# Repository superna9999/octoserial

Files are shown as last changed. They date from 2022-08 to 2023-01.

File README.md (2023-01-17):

# OctoSerial

USB High-Speed to 8x RS-232 TTL level with the CH348Q IC.

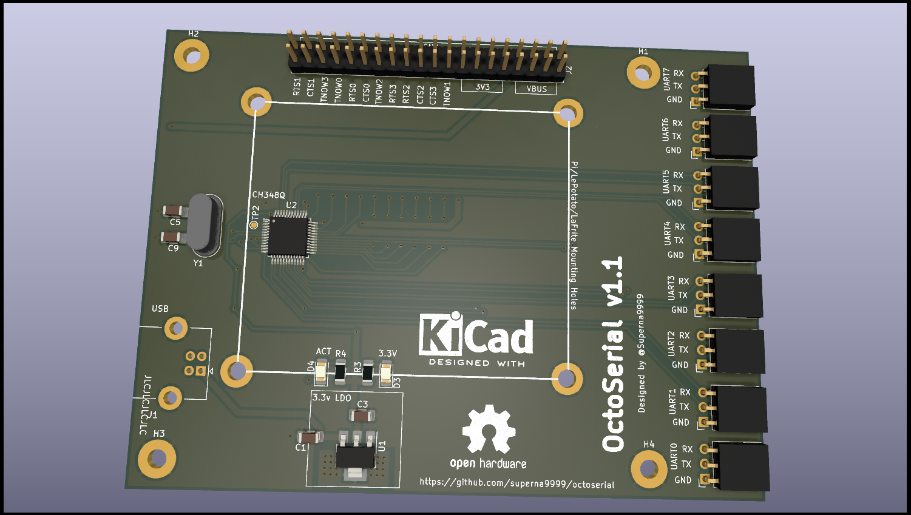
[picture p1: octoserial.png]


Schematics: [octoserial.pdf](octoserial.pdf)

Changelog
---------

Version 1.1:
- Production version with 40pins headers with GPIOs + 3v3 + VBUS & GND

Version 0.1:
- Initial prototype with CH348Q samples

LICENCE
-------

```
Apache License Version 2.0
```

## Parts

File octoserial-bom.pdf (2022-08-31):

octoserial.csv

Page 1

Designator | Package | Quantity Designation
C1,C3 | C_1206_3216Metric_Pad1.33x1.80mm_HandSolder | 2 10uF
U1 | SOT-223-3_TabPin2 | 1 AMS1117-3.3
Y1 | Crystal_HC49-4H_Vertical | 1 8MHz
U2 | LQFP-48_7x7mm_P0.5mm | 1 CH348Q
C9,C5 | C_1206_3216Metric_Pad1.33x1.80mm_HandSolder | 2 22pF
D3,D4 | LED_1206_3216Metric_Pad1.42x1.75mm_HandSolder | 2 LED
R3,R4 | R_1206_3216Metric_Pad1.30x1.75mm_HandSolder | 2 2K
J1 | USB_B_Lumberg_2411_02_Horizontal | 1 USB_OTG
C2,C15,C16,C17,C14 C_1206_3216Metric_Pad1.33x1.80mm_HandSolder | 4 100nF
R1,R2 | R_1206_3216Metric_Pad1.30x1.75mm_HandSolder | 2 4.7K

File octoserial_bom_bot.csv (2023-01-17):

Comment | Designator | Footprint | LCSC Part #
0.1uF | C2 | 1206 | C110255
100nF | C14 C15 C16 C17 | 1206 | C110255
4.7K | R1 R2 | 1206 | C17936

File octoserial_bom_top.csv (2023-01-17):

Comment | Designator | Footprint | LCSC Part #
10uF | C1 C3 | 1206 | C13585
22pF | C5 C9 | 1206 | C5137630
LED | D3 | 1206
LED | D4 | 1206 | C434438
USB_OTG | J1 |  | C46392
Conn_02x20_Odd_Even | J2 |  | C124383
Conn_01x03_Male | J3 J4 J5 J6 J7 J8 J9 J10 |  | C5116482
2K | R3 R4 | 1206 | C17944
AMS1117-3.3 | U1 | SOT-223-3 | C173386
CH348Q | U2 |  | C2979161
8MHz | Y1 |  | C21263

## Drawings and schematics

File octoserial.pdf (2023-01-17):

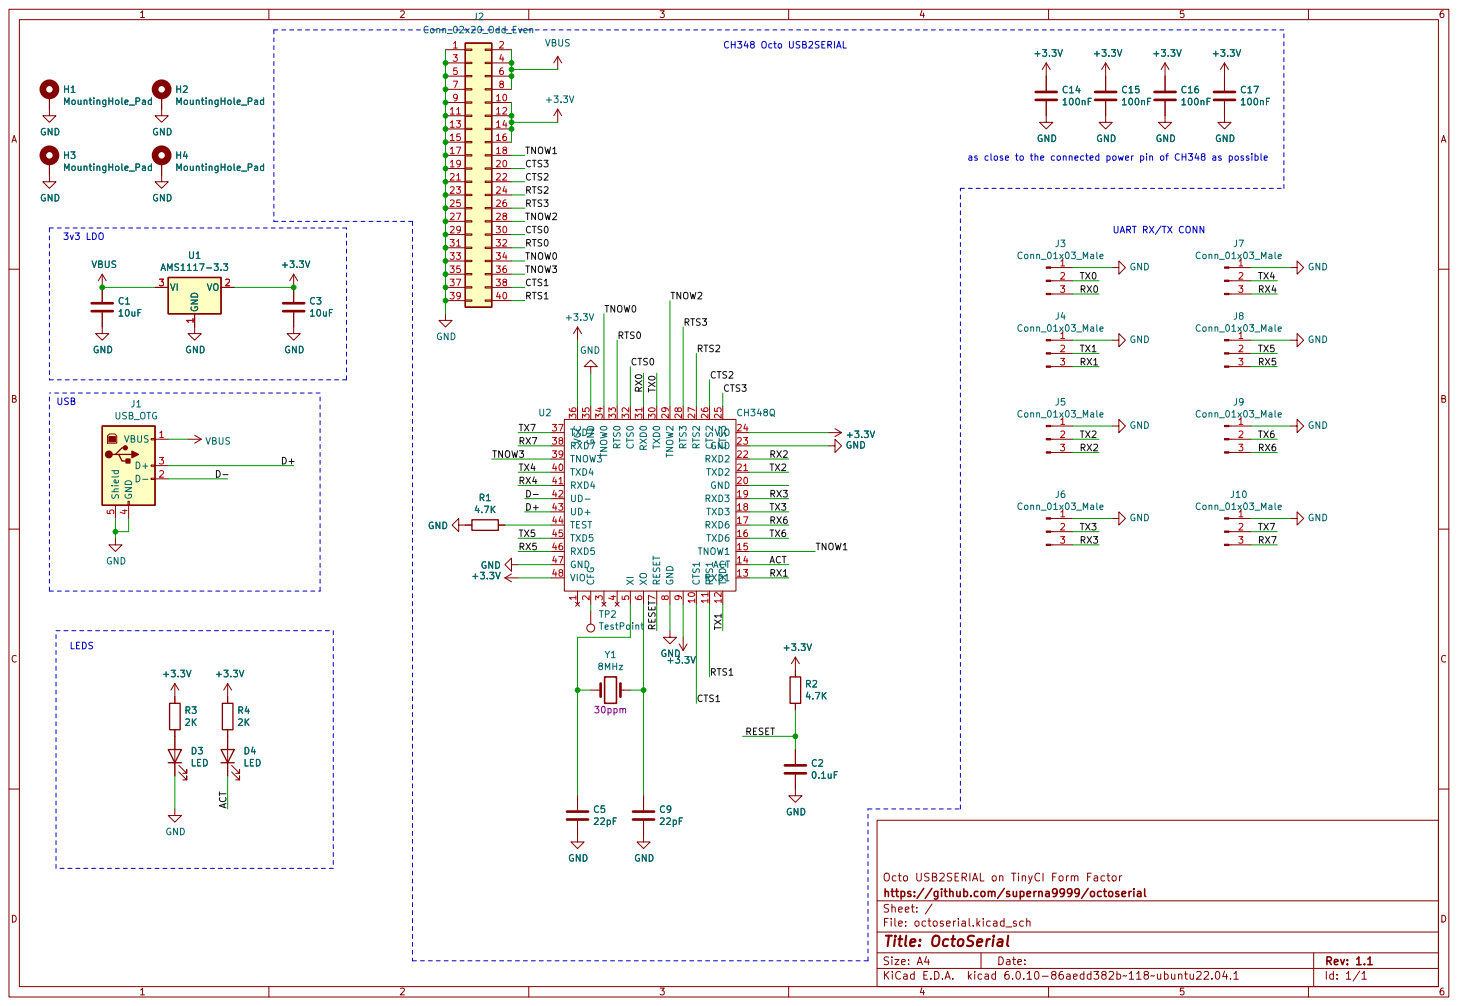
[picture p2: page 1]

9 | 10
11 | 12
13 | 14
15 | 16
17 | 18
19 | 20
21 | 22

as close to the connected power pin of CH348 as possible UART RX/TX CONN

25 | 26
27 | 28
29 | 30
31 | 32
33 | 34
35 | 36
37 | 38

3v3 LDO | +3.3V 10uF GND 10uF GND

4 TXD4 40 RXD4 41 UD- 42 UD+ 43 TEST 44 TXD5 45 RXD5 46 GND 47 VIO 48 XI 5 XO

Octo USB2SERIAL on TinyCI Form Factor
File: octoserial.kicad_sch Sheet: / https://github.com/superna9999/octoserial

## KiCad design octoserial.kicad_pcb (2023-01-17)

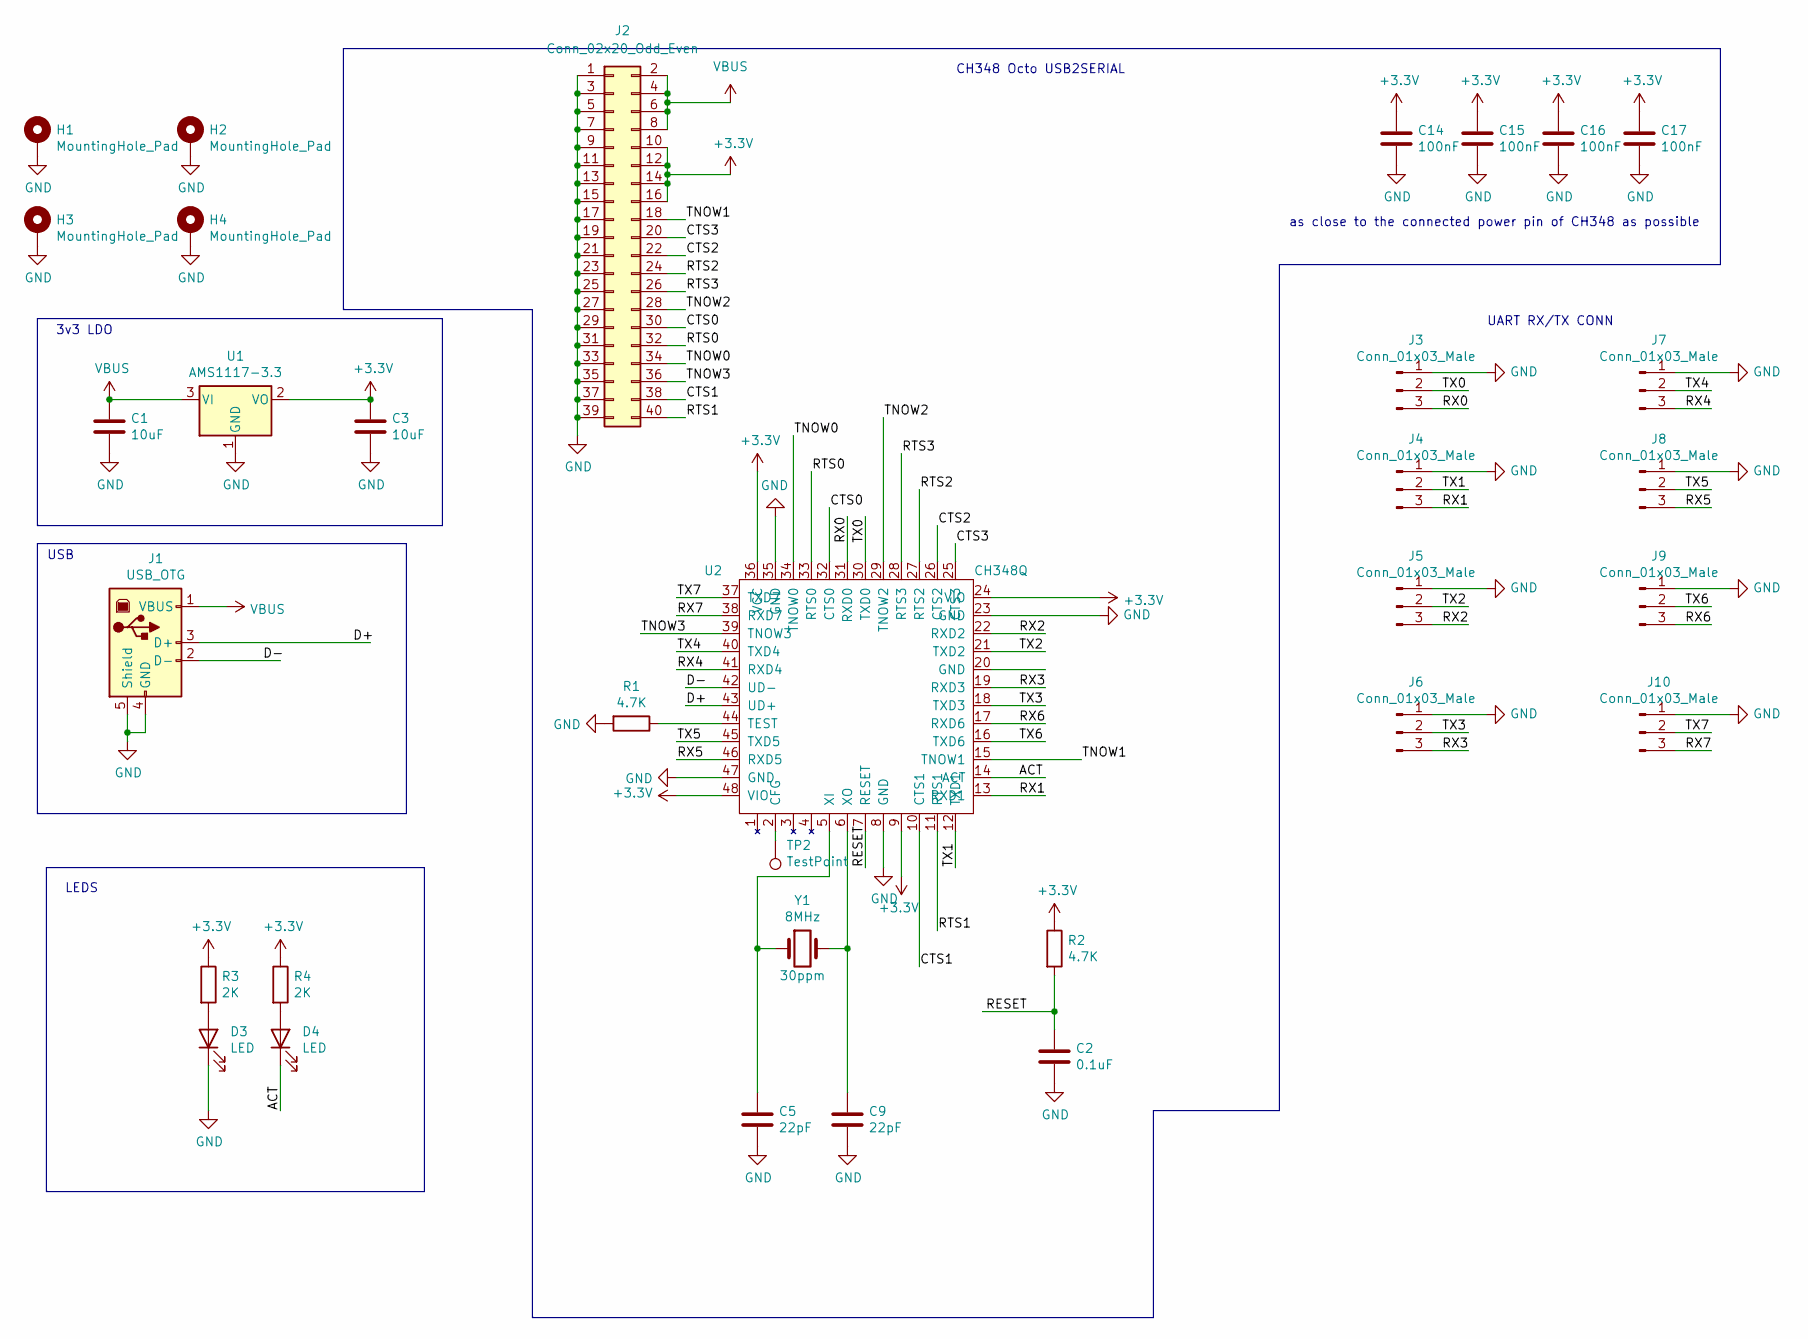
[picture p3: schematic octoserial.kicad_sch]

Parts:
C1, C3: 10uF; C_1206_3216Metric_Pad1.33x1.80mm_HandSolder; JLC 1206
C2: 0.1uF; C_1206_3216Metric_Pad1.33x1.80mm_HandSolder; JLC 1206
C5, C9: 22pF; C_1206_3216Metric_Pad1.33x1.80mm_HandSolder; JLC 1206
C14, C15, C16, C17: 100nF; C_1206_3216Metric_Pad1.33x1.80mm_HandSolder; JLC 1206
D3, D4: LED; LED_1206_3216Metric_Pad1.42x1.75mm_HandSolder; JLC 1206
H1, H2, H3, H4: MountingHole_Pad; MountingHole_3.2mm_M3_Pad
J1: USB_OTG; USB_B_Lumberg_2411_02_Horizontal; LCSC C46392
J2: Conn_02x20_Odd_Even; PinHeader_2x20_P2.54mm_Vertical; LCSC C124383
J3, J4, J5, J6, J7, J8, J9, J10: Conn_01x03_Male; PinSocket_1x03_P2.54mm_Horizontal; LCSC C5116482
R1, R2: 4.7K; R_1206_3216Metric_Pad1.30x1.75mm_HandSolder; JLC 1206
R3, R4: 2K; R_1206_3216Metric_Pad1.30x1.75mm_HandSolder; JLC 1206
TP2: TestPoint; TestPoint_Pad_D1.0mm
U1: AMS1117-3.3; SOT-223-3_TabPin2; JLC SOT-223-3
U2: CH348Q; LQFP-48_7x7mm_P0.5mm; LCSC C2979161
Y1: 8MHz; Crystal_HC49-4H_Vertical; LCSC C21263

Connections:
+3V3: C3.1, C14.1, C15.1, C16.1, C17.1, J2.10, J2.12, J2.14, J2.16, R2.1, R3.1, R4.1, U1.2 (VO), U2.9, U2.24 (VIO), U2.36 (VCC), U2.48 (VIO)
/ACT: D4.1 (K), U2.14 (ACT)
/CTS0: J2.30, U2.32 (CTS0)
/CTS1: J2.38, U2.10 (CTS1)
/CTS2: J2.22, U2.26 (CTS2)
/CTS3: J2.20, U2.25 (CTS3)
/D+: J1.3 (D+), U2.43 (UD+)
/D-: J1.2 (D-), U2.42 (UD-)
/RESET: C2.1, R2.2, U2.7 (RESET)
/RTS0: J2.32, U2.33 (RTS0)
/RTS1: J2.40, U2.11 (RTS1)
/RTS2: J2.24, U2.27 (RTS2)
/RTS3: J2.26, U2.28 (RTS3)
/RX0: J3.3, U2.31 (RXD0)
/RX1: J4.3, U2.13 (RXD1)
/RX2: J5.3, U2.22 (RXD2)
/RX3: J6.3, U2.19 (RXD3)
/RX4: J7.3, U2.41 (RXD4)
/RX5: J8.3, U2.46 (RXD5)
/RX6: J9.3, U2.17 (RXD6)
/RX7: J10.3, U2.38 (RXD7)
/TNOW0: J2.34, U2.34 (TNOW0)
/TNOW1: J2.18, U2.15 (TNOW1)
/TNOW2: J2.28, U2.29 (TNOW2)
/TNOW3: J2.36, U2.39 (TNOW3)
/TX0: J3.2, U2.30 (TXD0)
/TX1: J4.2, U2.12 (TXD1)
/TX2: J5.2, U2.21 (TXD2)
/TX3: J6.2, U2.18 (TXD3)
/TX4: J7.2, U2.40 (TXD4)
/TX5: J8.2, U2.45 (TXD5)
/TX6: J9.2, U2.16 (TXD6)
/TX7: J10.2, U2.37 (TXD7)
GND: C1.2, C2.2, C3.2, C5.2, C9.2, C14.2, C15.2, C16.2, C17.2, D3.1 (K), H1.1, H2.1, H3.1, H4.1, J1.4 (GND), J1.5 (Shield), J2.1, J2.3, J2.5, J2.7, J2.9, J2.11, J2.13, J2.15, J2.17, J2.19, J2.21, J2.23, J2.25, J2.27, J2.29, J2.31, J2.33, J2.35, J2.37, J2.39, J3.1, J4.1, J5.1, J6.1, J7.1, J8.1, J9.1, J10.1, R1.2, U1.1 (GND), U2.8 (GND), U2.23 (GND), U2.35 (GND), U2.47 (GND)
unnamed: C5.1, U2.5 (XI), Y1.1
unnamed: C9.1, U2.6 (XO), Y1.2
unnamed: D3.2 (A), R3.2
unnamed: D4.2 (A), R4.2
unnamed: R1.1, U2.44 (TEST)
unnamed: TP2.1, U2.2 (CFG)
VBUS: C1.1, J1.1 (VBUS), J2.2, J2.4, J2.6, J2.8, U1.3 (VI)

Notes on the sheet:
LEDS
UART RX/TX CONN
3v3 LDO
USB
as close to the connected power pin of CH348 as possible
CH348 Octo USB2SERIAL

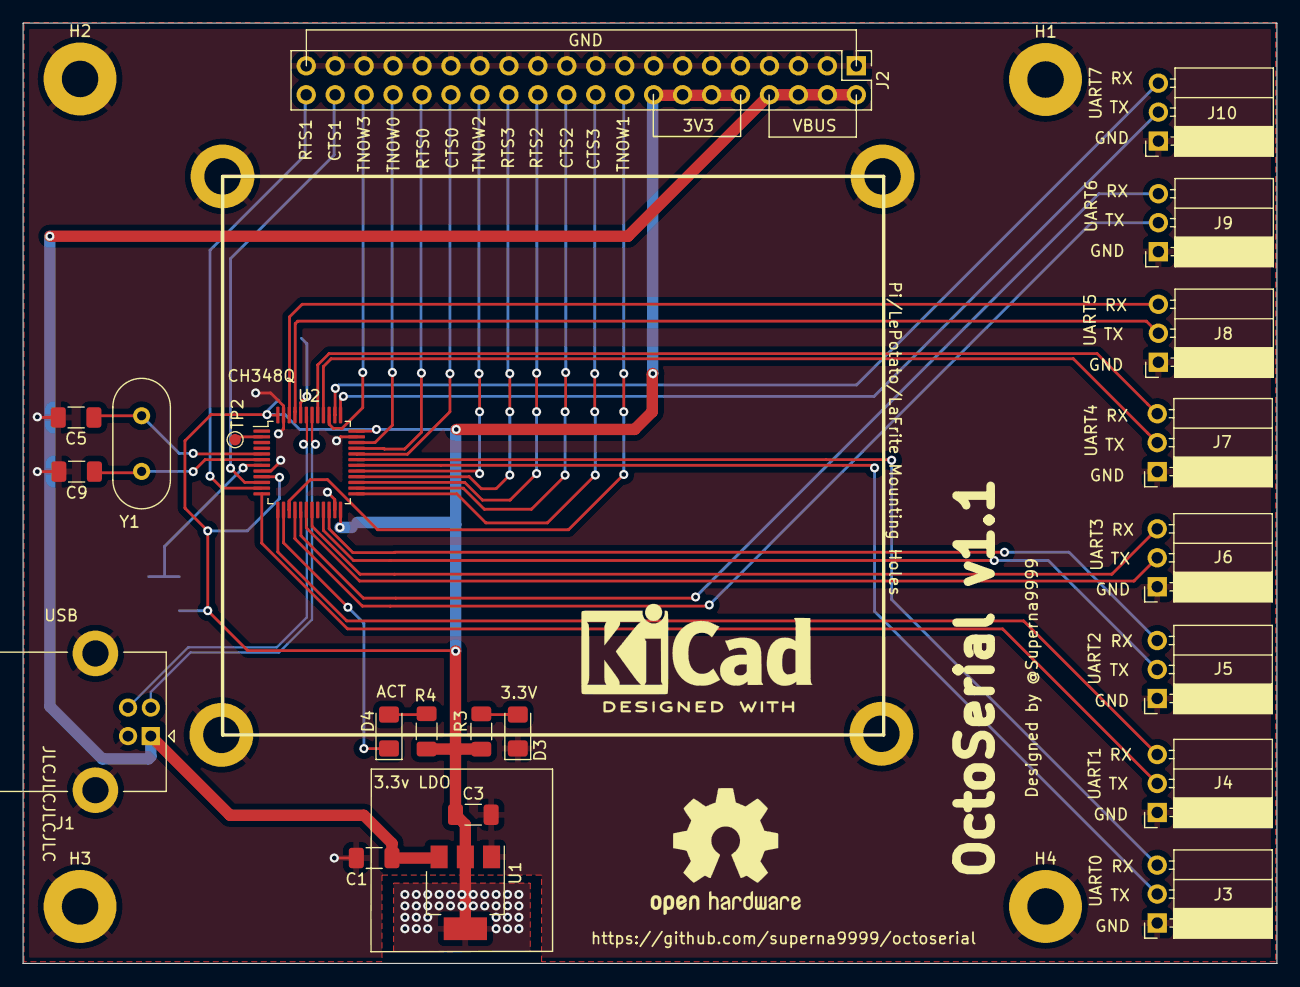
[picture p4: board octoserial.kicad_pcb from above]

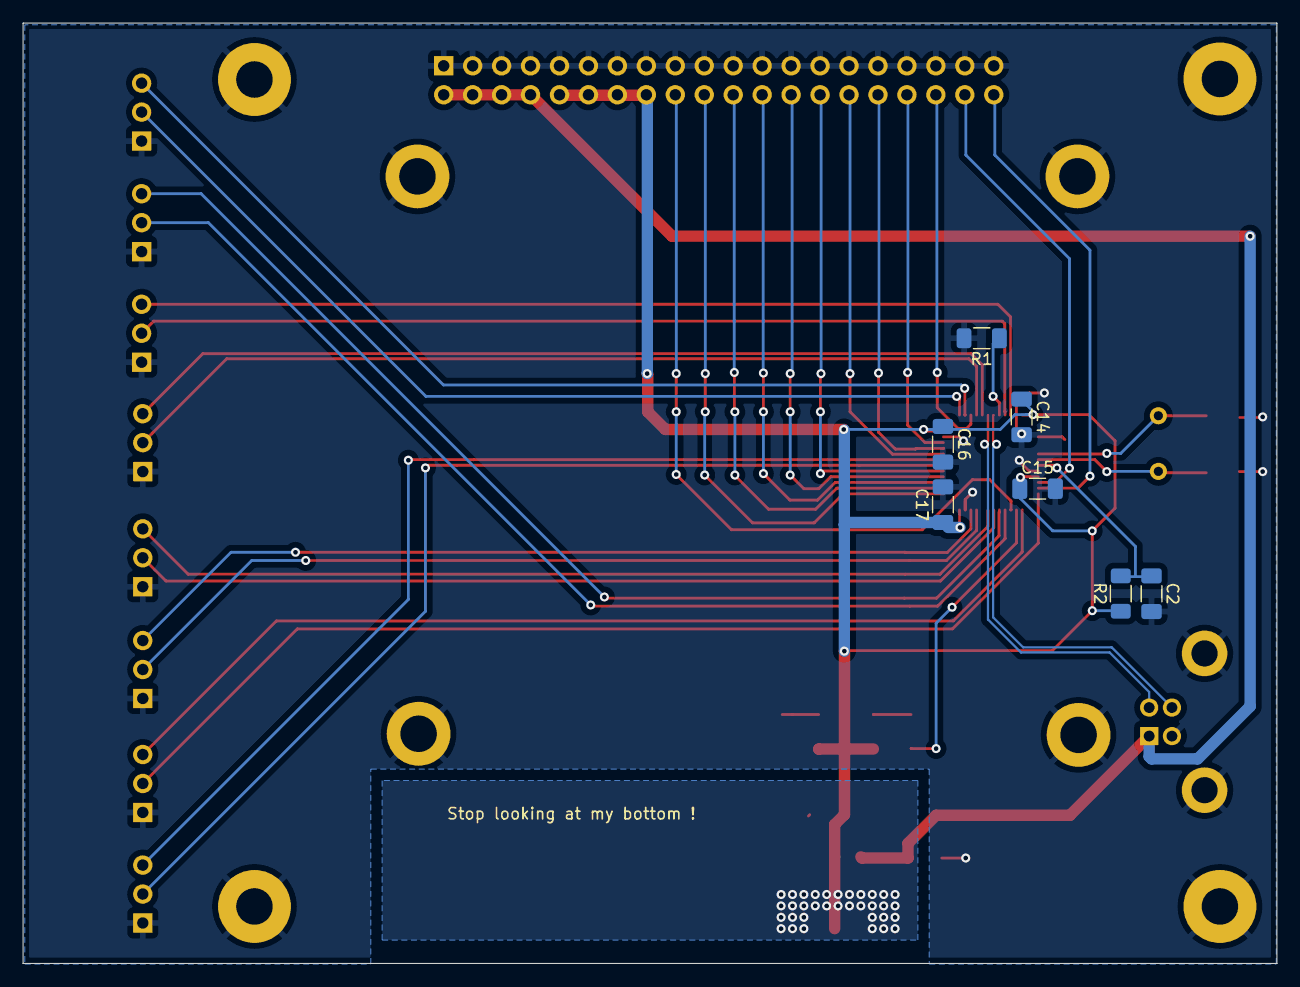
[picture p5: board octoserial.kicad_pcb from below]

Board: 2 copper layers, 110.0 x 82.5 mm, 33 parts (7 on the bottom side), 41 nets.

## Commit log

2022-08-31 Import v0.1
    [octoserial-B_Cu.gbr, octoserial-B_Mask.gbr, octoserial-B_Paste.gbr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]
2023-01-17 Add gpio/3.3 headers
    [octoserial.kicad_pcb, octoserial.kicad_sch]
2023-01-17 Add Kicad, OSHW + github URL on front silkscreen
    [octoserial.kicad_pcb]
2023-01-17 Add JPC & LCSC tags & regenerate gerber + bom CSVs
    [octoserial-B_Cu.gbr, octoserial-B_Mask.gbr, octoserial-B_Paste.gbr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]
